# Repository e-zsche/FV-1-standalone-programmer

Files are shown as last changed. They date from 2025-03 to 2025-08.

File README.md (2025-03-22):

# Micropython FV-1 flasher

Small project for flashing 24LC32A EEPROMs using any microcontroller which has enough flash and
is able to run Micropython. Just because, a raspberry pico is used.

<p float="left">
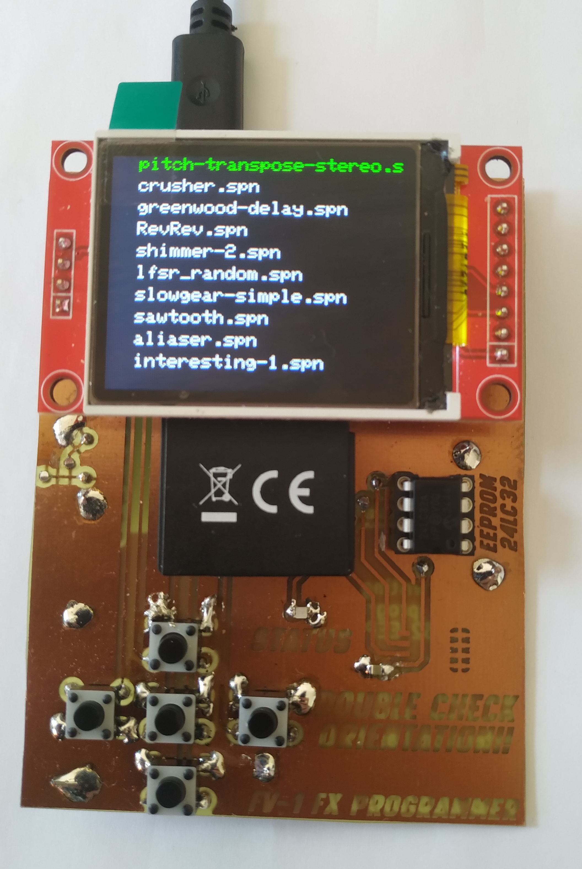
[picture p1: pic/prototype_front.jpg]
  
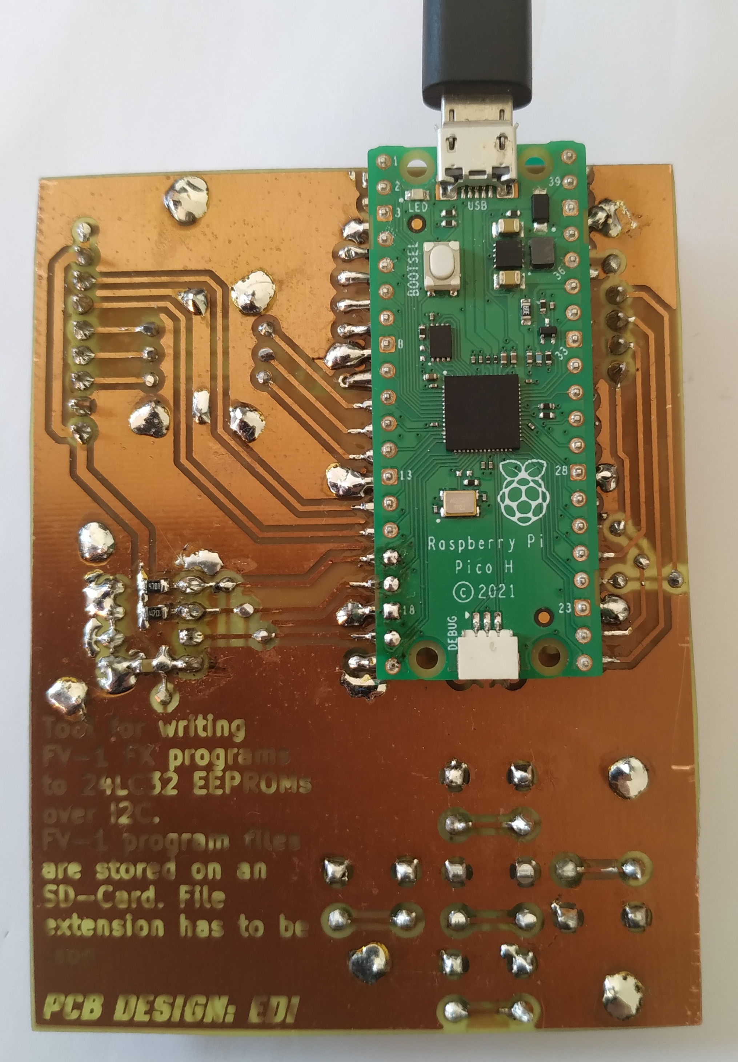
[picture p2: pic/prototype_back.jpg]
  
</p>

# Code

Huge thanks to ndf-zz for writing the asfv1 assembler. Without your work this would not be possible.
<https://github.com/ndf-zz/asfv1/>

As shlex is not in the standard Micropython library a copy of the source code is obtained and used
for running the asfv1 assembler. To get it running on the MCU one line is removed. So far this does
not seem to have an impact when running the code.

FV-1 programs are stored and read with a micro SD-card. All programs have to be in the root directory
and must have the `.spn` file extension to be found.

# Hardware

Everything is run by a Raspberry Pi Pico MCU.

User interface consists of:
- Display
- SD card slot
- EEPROM sockets
- Buttons

## Display

TFT display because it is cheaper than an OLED.
Has the SD card slot integrated.

## SD Card

Connected via SPI. Slot is Integrated into display module.

## EEPROM sockets

There are two positions on the PCB. One is for THT chips, the other for SMD chips.
SMD socket is the <a href="https://www.adafruit.com/product/4726">SOIC-8 socket from adafruit</a>

Make sure to insert the EEPROM with the correct orientation!!

## Buttons

In total there are five buttons arranged as a sort of D-Pad and a shift button.

Controls:
- up and down for scrolling through file list (faster scrolling when holding shift button)
- left and right for selecting program slot of selected file
- middle button
  * start programming (when not selecting slot)
  * selecting slot

# Obtain SPN files

Writing programs yourself for the FV-1 is good way to get some programs. Info on the assembly
language is a little harder to find than info on the FV-1 hardware. However there are some
sources inside a forum dating back to 2019:

- <a href="https://xenvn.com/threads/spin-fv-1-audio-effects.125">Spin FV-1 Audio Effects</a>
- <a href="https://xenvn.com/threads/spin-fv-1-instructions-and-syntax.122/">Spin FV-1 Instructions and Syntax</a>
- <a href="https://xenvn.com/threads/basics-of-the-lfos-in-the-spin-fv-1.123/">Basics of the LFOs in the Spin FV-1</a>

This is about all the info I could find on the assembly instructions itself...

Another wonderful source of programs is mstratman's collection of programs:

<https://mstratman.github.io/fv1-programs/>

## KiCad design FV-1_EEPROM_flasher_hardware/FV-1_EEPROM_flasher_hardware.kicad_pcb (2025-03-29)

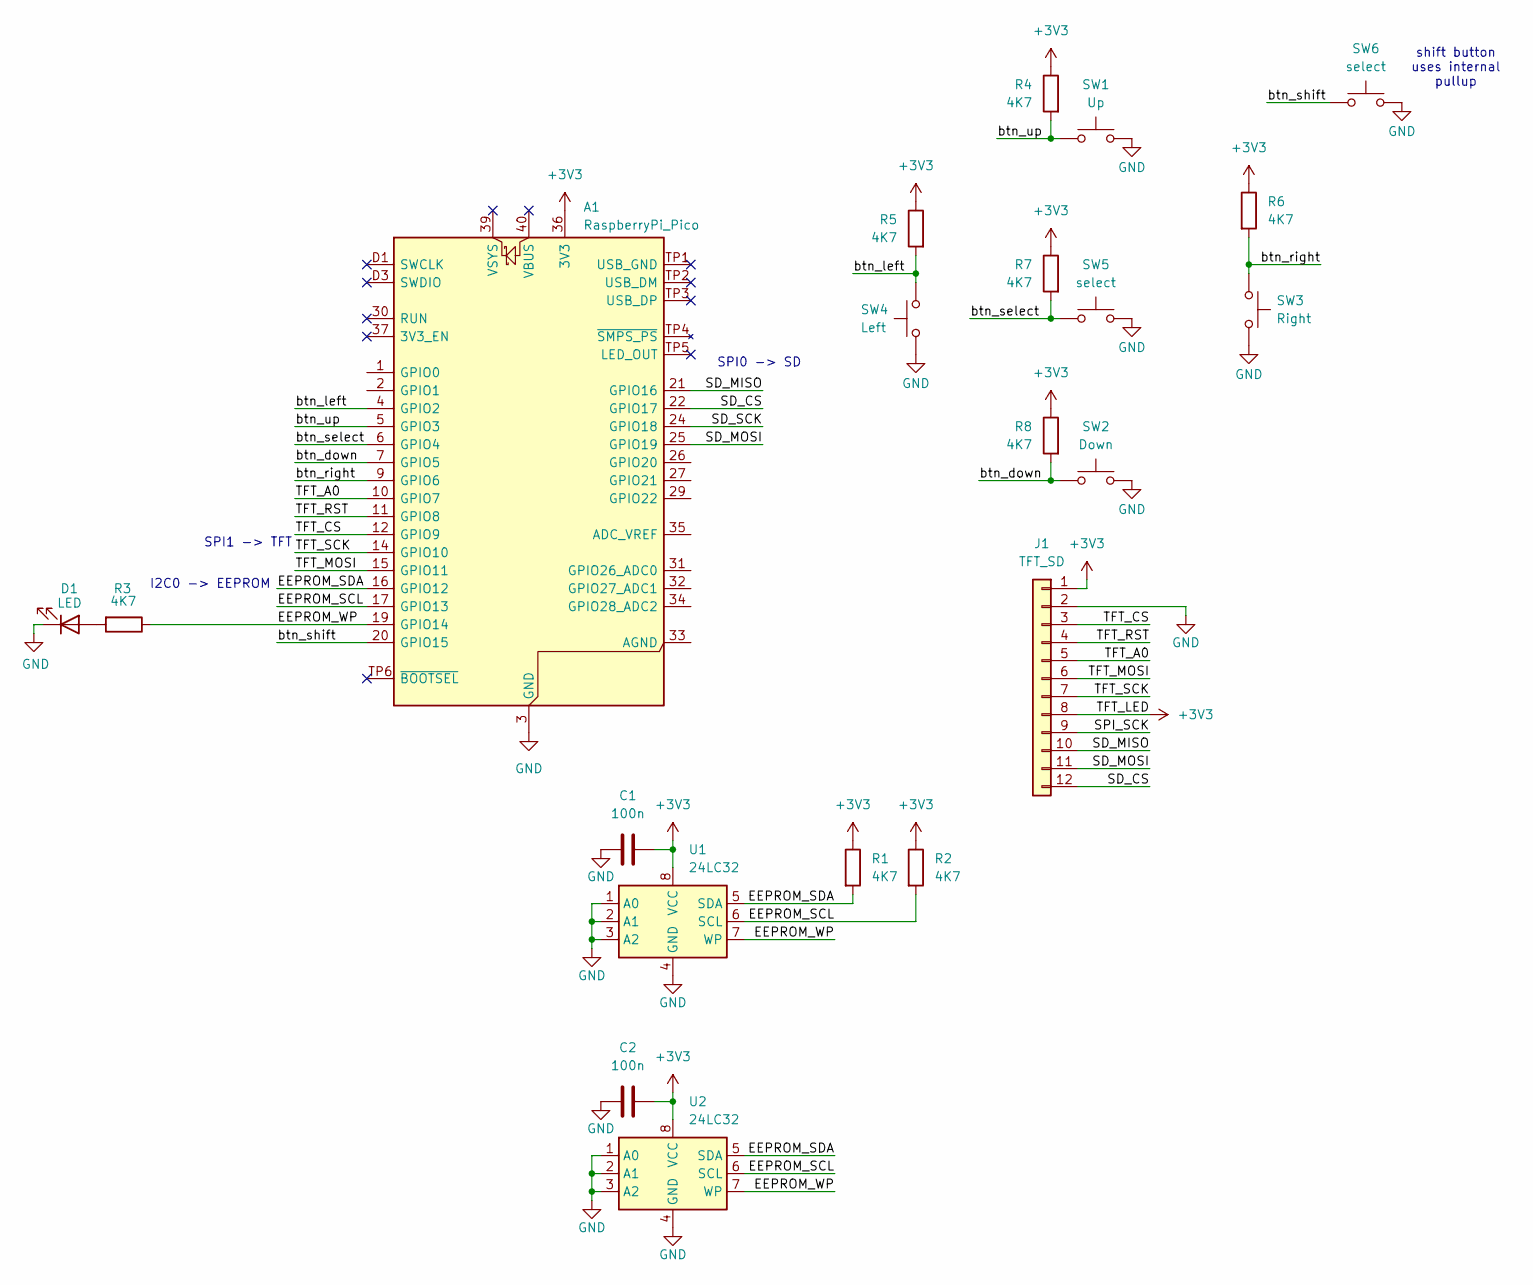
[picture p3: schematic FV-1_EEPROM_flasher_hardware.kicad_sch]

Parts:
A1: RaspberryPi_Pico; RaspberryPi_Pico_SMD
C1, C2: 100n; C_0805
D1: LED; LED_0805_2012Metric_Pad1.15x1.40mm_HandSolder
J1: TFT_SD; TFT_with_SD
R1, R2, R3, R4, R5, R6, R7, R8: 4K7; R_0805_2012Metric_Pad1.20x1.40mm_HandSolder
SW1: Up; SW_PUSH_6mm_H5mm
SW2: Down; SW_PUSH_6mm_H5mm
SW3: Right; SW_PUSH_6mm_H5mm
SW4: Left; SW_PUSH_6mm_H5mm
SW5, SW6: select; SW_PUSH_6mm_H5mm
U1: 24LC32; DIP-8_W7.62mm_Socket_LongPads
U2: 24LC32; SOIC-8_5.3x5.3mm_P1.27mm

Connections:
+3V3: A1.36 (3V3), C1.2, C2.2, J1.1, J1.8, R1.1, R2.1, R4.1, R5.1, R6.1, R7.1, R8.1, U1.8 (VCC), U2.8 (VCC)
/EEPROM_SCL: A1.17 (GPIO13), R2.2, U1.6 (SCL), U2.6 (SCL)
/EEPROM_SDA: A1.16 (GPIO12), R1.2, U1.5 (SDA), U2.5 (SDA)
/EEPROM_WP: A1.19 (GPIO14), R3.1, U1.7 (WP), U2.7 (WP)
/SD_CS: A1.22 (GPIO17), J1.12
/SD_MISO: A1.21 (GPIO16), J1.10
/SD_MOSI: A1.25 (GPIO19), J1.11
/SD_SCK: A1.24 (GPIO18)
/SPI_SCK: J1.9
/TFT_A0: A1.10 (GPIO7), J1.5
/TFT_CS: A1.12 (GPIO9), J1.3
/TFT_MOSI: A1.15 (GPIO11), J1.6
/TFT_RST: A1.11 (GPIO8), J1.4
/TFT_SCK: A1.14 (GPIO10), J1.7
/btn_down: A1.7 (GPIO5), R8.2, SW2.1
/btn_left: A1.4 (GPIO2), R5.2, SW4.2
/btn_right: A1.9 (GPIO6), R6.2, SW3.1
/btn_select: A1.6 (GPIO4), R7.2, SW5.1
/btn_shift: A1.20 (GPIO15), SW6.1
/btn_up: A1.5 (GPIO3), R4.2, SW1.1
GND: A1.3 (GND), A1.8 (GND), A1.13 (GND), A1.18 (GND), A1.23 (GND), A1.28 (GND), A1.38 (GND), A1.D2 (GND), C1.1, C2.1, D1.1 (K), J1.2, SW1.2, SW2.2, SW3.2, SW4.1, SW5.2, SW6.2, U1.1 (A0), U1.2 (A1), U1.3 (A2), U1.4 (GND), U2.1 (A0), U2.2 (A1), U2.3 (A2), U2.4 (GND)
unnamed: D1.2 (A), R3.2

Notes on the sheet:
I2C0 -> EEPROM
SPI1 -> TFT
SPI0 -> SD
shift button uses internal pullup

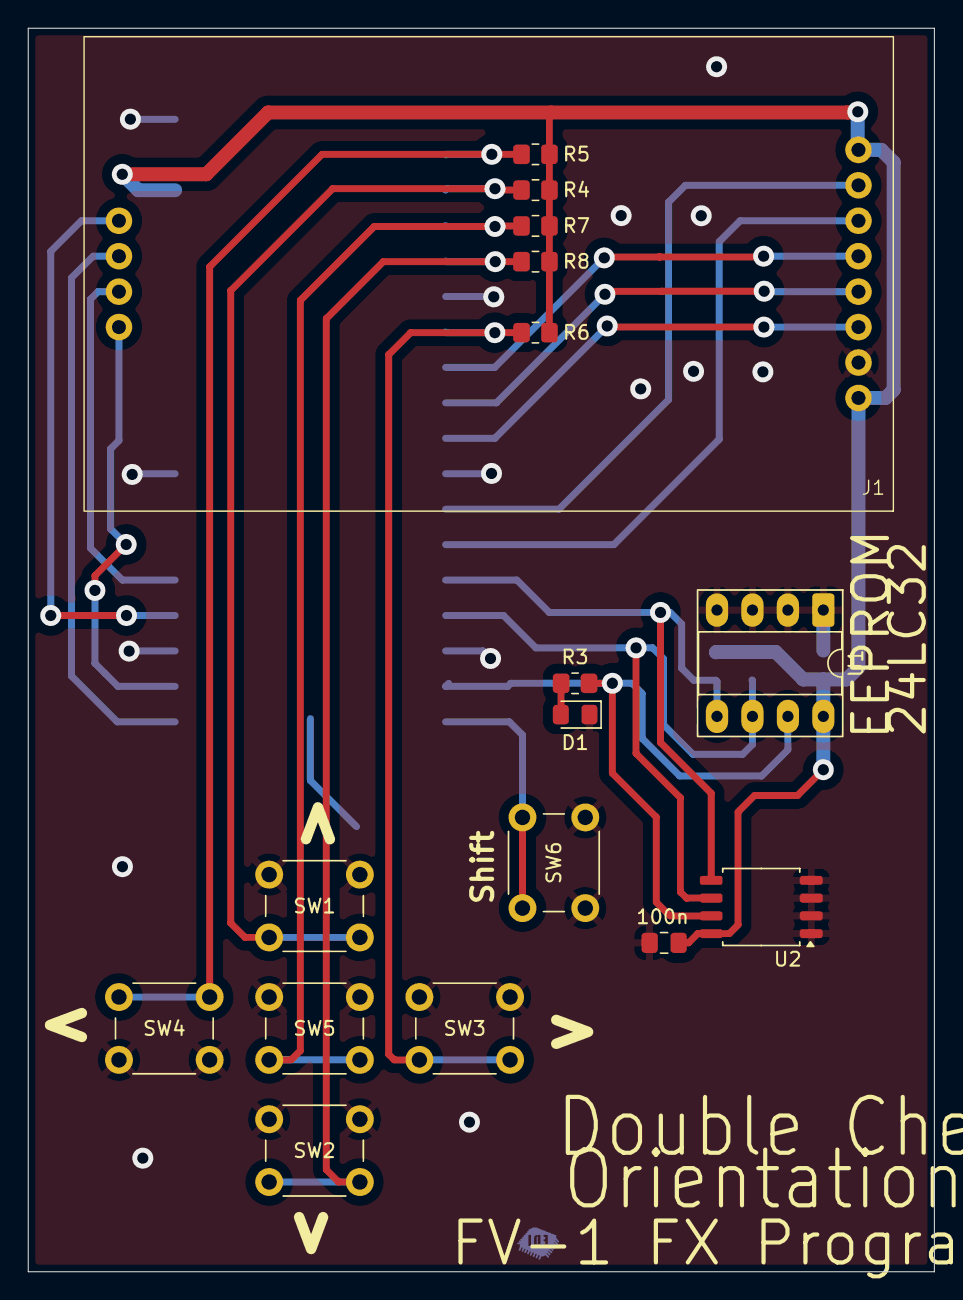
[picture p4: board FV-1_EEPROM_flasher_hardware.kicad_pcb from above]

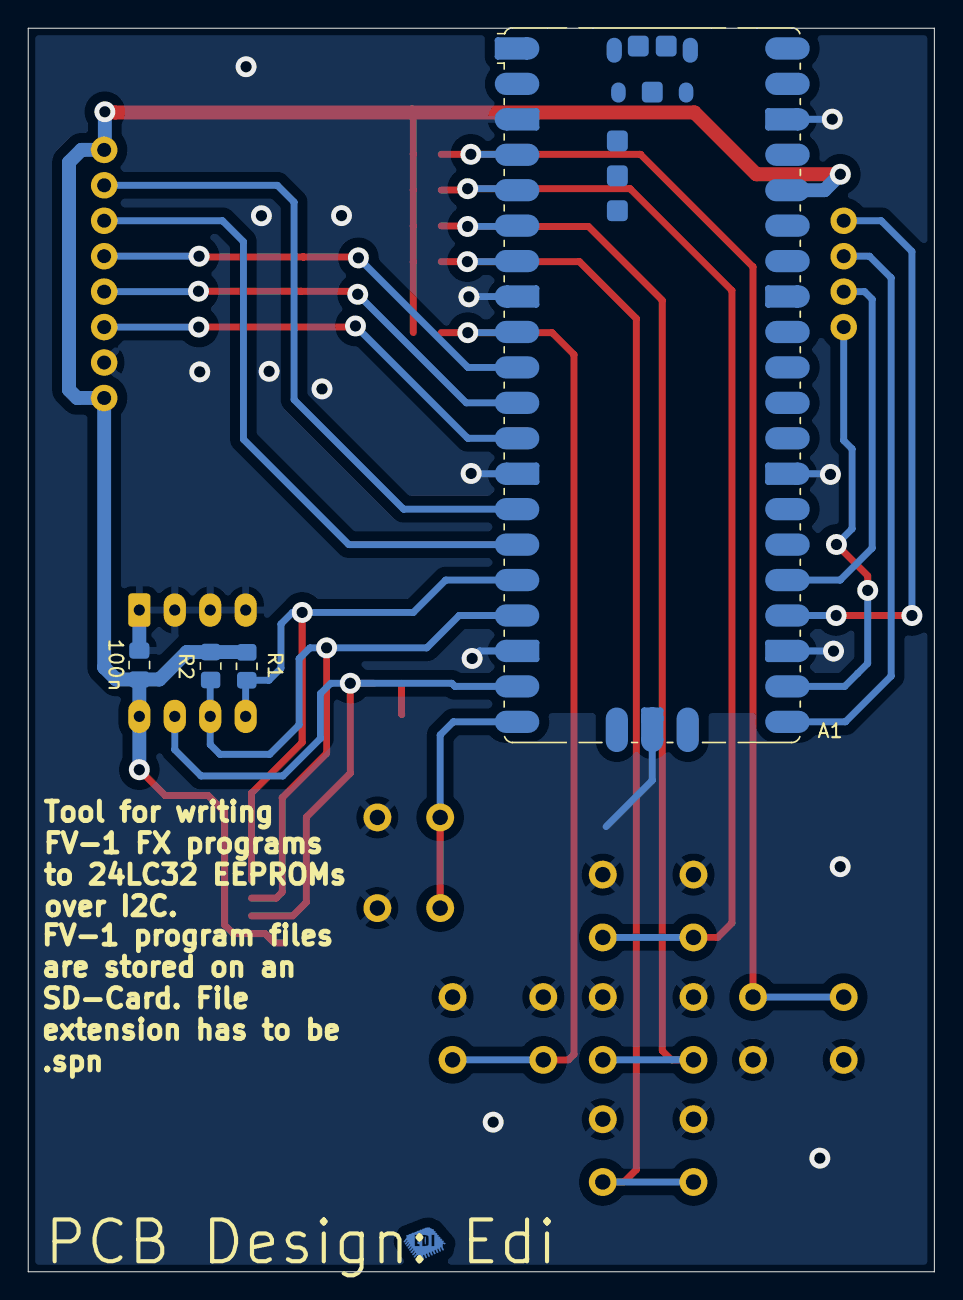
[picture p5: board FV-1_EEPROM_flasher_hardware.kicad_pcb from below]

Board: 2 copper layers, 64.9 x 89.1 mm, 22 parts (5 on the bottom side), 20 nets.

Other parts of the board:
Ref**: Val**; PCB_EDI_logo

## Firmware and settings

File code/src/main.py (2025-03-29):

import os
import time
import uos
import gc

from machine import Pin, SPI, I2C
from micropython import const  # type: ignore
from sysfont import sysfont

from lib import asfv1
from lib.ST7735 import TFT
from lib.sdcard import SDCard
from lib import widgets
from lib.EEPROM import EEPROM_24LC32A

CHAR_WIDTH = 6

TFT_WIDTH  = 160 # px
TFT_HEIGHT = 128 # px

btn_up      = Pin(3, Pin.IN, Pin.PULL_UP)
btn_down    = Pin(5, Pin.IN, Pin.PULL_UP)
btn_left    = Pin(2, Pin.IN, Pin.PULL_UP)
btn_right   = Pin(6, Pin.IN, Pin.PULL_UP)
btn_select  = Pin(4, Pin.IN, Pin.PULL_UP)
btn_shift   = Pin(15, Pin.IN, Pin.PULL_UP)

# TFT init
WHITE = const(0XFFFFFF)
tft_spi = SPI(1, baudrate=10000000, sck=Pin(10), mosi=Pin(11))
dc = 7; reset = 8; cs = 9;
tft = TFT(tft_spi, dc, reset, cs)
tft.rotation(3)
tft.initr()
tft.rgb(True)
tft.fill(TFT.BLACK)
tft.text(( 0,  1), "booting...", TFT.WHITE, sysfont, 1)

# EEPROM I2C
#eeprom_i2c = I2C(0, scl=Pin(13), sda=Pin(12))
eeprom = EEPROM_24LC32A(scl=Pin(13), sda=Pin(12), wp=Pin(14, Pin.OUT))

# SD Card init
sd_spi = SPI(0, baudrate=2000000,
             polarity=0, phase=0, bits=8,
             sck=Pin(18), mosi=Pin(19), miso=Pin(16))
try:
    sd = SDCard(sd_spi, cs=Pin(17))
except OSError:
    tft.fill(TFT.BLACK)
    tft.text(( 1,  1), "ERROR:", TFT.RED, sysfont, 2)
    tft.text(( 1,  30), "no SD card found...", TFT.WHITE, sysfont, 1)
    tft.text(( 1,  42), "check the card", TFT.WHITE, sysfont, 1)
    while 1:
        pass

SPN_ROOT_DIR = "/sd"

vfs  = uos.VfsFat(sd)
os.mount(sd, SPN_ROOT_DIR)

global TXT_SIZE, Y_START

TXT_SIZE = 1
Y_START = 2

fv_files = [f for f in os.listdir(SPN_ROOT_DIR) if f.endswith(".spn")]
if len(fv_files) < 1:
    tft.fill(TFT.BLACK)
    tft.text(( 1,  1), "ERROR:", TFT.RED, sysfont, 2)
    tft.text(( 1,  30), "no .spn files found", TFT.WHITE, sysfont, 1)
    tft.text(( 1,  42), "check your SD card", TFT.WHITE, sysfont, 1)
    tft.text(( 1,  54), "and retry", TFT.WHITE, sysfont, 1)
    while 1:
        pass

cursor_pos = 0
MAX_FILE_ON_DISP = 9
file_list_offs = [0, MAX_FILE_ON_DISP]

slot_pos = 0
fv_program_slots = {
        0: "",
        1: "",
        2: "",
        3: "",
        4: "",
        5: "",
        6: "",
        7: "",
        }

def draw_file_list():
    Y_START = 1
    for y_offs, name in enumerate(fv_files[ file_list_offs[0] : file_list_offs[1]+1 ]):
        color = TFT.WHITE
        if name in fv_program_slots.values():
            # TODO: show the slot
            inv_map = {v: k for k, v in fv_program_slots.items()}
            tft.text(( 1,  Y_START ), str(inv_map[name]+1), color, sysfont, TXT_SIZE, nowrap=True)
            pass
        if y_offs + file_list_offs[0] == cursor_pos:
            # highlight selected file
            color = TFT.GREEN
        tft.text(( 15,  Y_START ), name, color, sysfont, TXT_SIZE, nowrap=True)
        Y_START += 4+TXT_SIZE*8


############################
# MAIN
############################

# TODO: make a menu

tft.fill(TFT.BLACK)
draw_file_list()

print(file_list_offs)

# TODO: main loop
last_ticks_btn = 0
last_ticks_slot_blink = 0

is_slot_selection = False
sel_blink = False
slot_to_change = 0
while(1):
    #####################
    # SCROLL FILES
    #####################
    scroll_mul = 1
    if not is_slot_selection and time.ticks_ms() - last_ticks_btn > 250 and btn_down.value() == 0:
        tft.fill(TFT.BLACK)
        # scroll down
        if btn_shift.value() == 0:
            scroll_mul = MAX_FILE_ON_DISP

        cursor_pos += 1 * scroll_mul

        if cursor_pos > file_list_offs[1]:
            file_list_offs[0] = file_list_offs[0] + 1 * scroll_mul
            file_list_offs[1] = file_list_offs[1] + 1 * scroll_mul

        if file_list_offs[1] > len(fv_files)-1:
            # roll over to beginning
            file_list_offs[0] = 0
            file_list_offs[1] = MAX_FILE_ON_DISP

        if cursor_pos > len(fv_files)-1:
            cursor_pos = 0

        # redraw screen
        draw_file_list()
        # update btn debounce
        last_ticks_btn = time.ticks_ms()
        print(f"scroll down: cursor_pos {cursor_pos} | f: {fv_files[cursor_pos]}")

    if not is_slot_selection and time.ticks_ms() - last_ticks_btn > 250 and btn_up.value() == 0:
        tft.fill(TFT.BLACK)
        print(f"start scroll:\ncursor_pos: {cursor_pos}\noffs[0]: {file_list_offs[0]}\noffs[1]: {file_list_offs[1]}")
        # scroll up
        if btn_shift.value() == 0:
            scroll_mul = MAX_FILE_ON_DISP

        cursor_pos = cursor_pos - 1 * scroll_mul
        print(f"decrease cursor_pos: cursor_pos: {cursor_pos}")

        if cursor_pos < file_list_offs[0]:
            file_list_offs[0] = file_list_offs[0] - 1 * scroll_mul
            print(f"decrease index[0]: {file_list_offs[0]}")
            file_list_offs[1] = file_list_offs[1] - 1 * scroll_mul
            print(f"decrease index[1]: {file_list_offs[1]}")

        if file_list_offs[0] < 0:
            # roll over
            file_list_offs[0] = len(fv_files)-1 - MAX_FILE_ON_DISP
            file_list_offs[1] = len(fv_files)-1
            print("roll over")
            print(f"index[0]: {file_list_offs[0]}")
            print(f"index[1]: {file_list_offs[1]}")

        if cursor_pos < 0:
            print(f"cursor_pos: {cursor_pos}")
            cursor_pos = len(fv_files)-1

        draw_file_list()
        # update btn debounce
        last_ticks_btn = time.ticks_ms()
        print(f"scroll up: cursor_pos {cursor_pos} | f: {fv_files[cursor_pos]}")

    #####################
    # SLOT SELECTION
    #####################

    if is_slot_selection and time.ticks_ms() - last_ticks_btn > 250 and btn_select.value() == 0:
        # select program for slot
        if not slot_pos == -1:
            # check for duplicates
            if fv_files[cursor_pos] in fv_program_slots.values():
                print("program in use")
                # delete occurence
                for k in fv_program_slots.keys():
                    if fv_program_slots[k] == fv_files[cursor_pos]:
                        fv_program_slots[k] = ""
            fv_program_slots[slot_pos] = fv_files[cursor_pos]
            print(f"slot {slot_pos}: {fv_files[cursor_pos]}")
        if slot_pos == -1 and fv_files[cursor_pos] in fv_program_slots.values():
            # delete slot
            print(f"delete slot")
            for k in fv_program_slots.keys():
                if fv_program_slots[k] == fv_files[cursor_pos]:
                    fv_program_slots[k] = ""
        print(fv_program_slots)
        is_slot_selection = False
        print("stop slot selection")
        tft.fill(TFT.BLACK)
        draw_file_list()
        last_ticks_btn = time.ticks_ms()

    if is_slot_selection and time.ticks_ms() - last_ticks_slot_blink > 200:
        pos = (2, Y_START+(cursor_pos-file_list_offs[0])*TXT_SIZE*11+4)
        # blink slot selection num
        if sel_blink and slot_pos >= 0:
            color = TFT.GREEN
            if fv_program_slots[slot_pos] != "":
                color = TFT.YELLOW
            tft.text(pos, f"{slot_pos+1}", color, sysfont, TXT_SIZE)
        elif sel_blink and slot_pos == -1:
            tft.text(pos, "-", TFT.WHITE, sysfont, TXT_SIZE)
        else:
            tft.fillrect(pos, (10,10), TFT.BLACK)
        sel_blink = not sel_blink
        last_ticks_slot_blink = time.ticks_ms()

    # change slot of program
    if time.ticks_ms() - last_ticks_btn > 250 and btn_left.value() == 0:
        if not is_slot_selection:
            is_slot_selection = True
        else:
            slot_pos = slot_pos-1
        if slot_pos < -1:
            slot_pos = 7
        last_ticks_btn = time.ticks_ms()

    if time.ticks_ms() - last_ticks_btn > 250 and btn_right.value() == 0:
        if not is_slot_selection:
            is_slot_selection = True
        else:
            slot_pos = slot_pos+1
        if slot_pos > 7:
            slot_pos = -1
        last_ticks_btn = time.ticks_ms()

    #####################
    # PROGRAM EEPROM
    #####################
    if not is_slot_selection and time.ticks_ms() - last_ticks_btn > 250 and btn_select.value() == 0:
        # program eeproms as blocking call
        tft.fill(TFT.BLACK)
        has_eeprom = True
        if len(eeprom.i2c.scan()) == 0:
            has_eeprom = False
        if not len([i for i in fv_program_slots.values() if i ==""]) >= 8 and has_eeprom:
            print("start programming")
            eeprom_addr = eeprom.i2c.scan()[0]
            # something in dict
            for slot in range(8):
                txt_pos = (1, 2+slot*10)
                if fv_program_slots[slot] == "":
                    tft.text(txt_pos, f"slot{slot+1} empty", TFT.WHITE, sysfont, 1)
                    continue
                print(f"slot {slot}: {fv_program_slots[slot]}")
                spn_content = b""
                gc.collect() # free some RAM for this!
                with open(f"{SPN_ROOT_DIR}/{fv_program_slots[slot]}", "rb") as f:
                    try:
                        for line in f.readlines():
                            if line.startswith(b";") \
                                or line.startswith(b"\r") \
                                or line.startswith(b"\n"):
                                continue
                            spn_content += line.split(b";")[0]
                    except MemoryError:
                        # TODO: wat to do with Error
                        print("MemoryError: file content too big for RAM")
                        tft.text(txt_pos, f"slot{slot+1} ERROR:file too big!", TFT.RED, sysfont, 1)
                        continue

                encoding = 'utf-8'
                # check for BOM
                if len(spn_content) > 2 and spn_content[0] == 0xFF and spn_content[1] == 0xFE:
                    encoding = 'utf-16le'
                elif len(spn_content) > 2 and spn_content[0] == 0xFE and spn_content[1] == 0xFF:
                    encoding = 'utf-16be'
                # or assume windows encoded 'ANSI'
                elif len(spn_content) > 7 and spn_content[7] == 0x00:
                    encoding = 'utf-16le'

                fv1_parser = asfv1.fv1parse(spn_content.decode(encoding, 'replace'),
                                            clamp=True, spinreals=True,
                                            wfunc=asfv1.warning, efunc=asfv1.error
                                           )
                for attempt in range(3):
                    try:
                        fv1_parser.parse()
                    except asfv1.ASFV1Error:
                        if attempt == 0:
                            fv1_parser.doclamp = False
                            fv1_parser.spinreals = True
                        elif attempt == 1:
                            fv1_parser.doclamp = True
                            fv1_parser.spinreals = False
                        elif attempt == 2:
                            fv1_parser.doclamp = False
                            fv1_parser.spinreals = False
                        print("assembler error. trying again")
                        continue
                    else:
                        # reset to startign flags
                        print("did work now")
                        fv1_parser.doclamp = True
                        fv1_parser.spinreals = True
                        break
                else:
                    # TODO: program does not assemble
                    tft.text(txt_pos, f"slot{slot+1} ERROR:file not valid!", TFT.RED, sysfont, 1)
                    continue

                # write to EEPROM
                mem_offs = 0x200 * slot
                eeprom.write_data(mem_offs, fv1_parser.program)
                if fv1_parser.program == eeprom.read_data(mem_offs, 0x200):
                    print("program check OK!")
                    tft.text(txt_pos, f"slot{slot+1} okay!", TFT.WHITE, sysfont, 1)
                else:
                    tft.text(txt_pos, f"slot{slot+1} ERROR:not written!", TFT.RED, sysfont, 1)

                # free RAM so it does not fill while assembling
                del spn_content
                del fv1_parser
                gc.collect() # free some RAM for this!

            tft.text((10, txt_pos[1]+22), f"press select button", TFT.YELLOW, sysfont, 1)
            tft.text((10, txt_pos[1]+34), f"to continue", TFT.YELLOW, sysfont, 1)
            while btn_select.value():
                pass
        elif len([i for i in fv_program_slots.values() if i ==""]) >= 8:
            print("no files selected")
            # dict empty
            tft.text((2, 10), "No", TFT.RED, sysfont, 3)
            tft.text((2, 40), "programs", TFT.RED, sysfont, 3)
            tft.text((2, 70), "selected", TFT.RED, sysfont, 3)
            time.sleep(3)
        elif not has_eeprom:
            print("no eeprom found")
            tft.text((2, 10), "No", TFT.RED, sysfont, 3)
            tft.text((2, 40), "EEPROM", TFT.RED, sysfont, 3)
            tft.text((2, 70), "found", TFT.RED, sysfont, 3)
            time.sleep(3)

        # reset to selection screen
        tft.fill(TFT.BLACK)
        draw_file_list()
        last_ticks_btn = time.ticks_ms()

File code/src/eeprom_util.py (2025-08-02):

from machine import Pin, I2C
import time

wp = Pin(14, Pin.OUT)
wp.on()
i2c = I2C(0, scl=Pin(13), sda=Pin(12))

def read_eeprom(mem_addr, num_bytes):
    return i2c.readfrom_mem(0x50, mem_addr, num_bytes, addrsize=16)

def read_program(num_program):
    if num_program < 1 or num_program > 8:
        print("program number must be between 1 or 8")
        return
    return read_eeprom(0x200*(num_program-1), 0x200)

def write_eeprom(mem_addr, byte_buf):
    if len(byte_buf) < 32:
        wp.off()
        i2c.writeto_mem(0x50, mem_addr, byte_buf, addrsize=16)
        wp.on()
        return

    curr_idx = 0
    n_slices = int(len(byte_buf)/32)
    for i in range(n_slices):
        mem_offs = mem_addr + i*32
        wp.off()
        i2c.writeto_mem(0x50, mem_offs, byte_buf[curr_idx:curr_idx+32], addrsize=16)
        wp.on()
        curr_idx += 32
        time.sleep(0.005) # 5ms wait time needed by eeprom
    i+=1
    mem_offs = mem_addr + i*32
    wp.off()
    i2c.writeto_mem(0x50, mem_offs, byte_buf[curr_idx:curr_idx+32], addrsize=16)
    print(curr_idx)
    wp.on()

def clone_eeprom():
    print("reading from eeprom")

    if not 0x50 in i2c.scan():
        print("no eeprom found. Aborting")
        return

    if input("start cloning [y/N]").lower() not in ["y", "yes"]:
        print("Aborting")
        return

    # read all programs
    content = b""
    for i in range(8):
        content += read_eeprom(i*0x200, 0x200)
    print("read successful")

    if input("insert empty EEPROM and continue [y/N]").lower() not in ["y", "yes"]:
        print("Aborting")
        return

    write_eeprom(0, content)

    print("checking content")
    content2 = b""
    for i in range(8):
        content2 += read_eeprom(i*0x200, 0x200)

    if not content == content2:
        print("ERROR: data verification failed")
        return

    print("SUCCESS: data verified and EEPROM is cloned")

def show_content():
    doc_str = """
    available functions:
      show_content()
        show this help text

      read_eeprom(mem_addr:int, num_bytes:int) -> bytes
        reads and returns num_bytes from eeprom starting at address mem_addr

      write_eeprom(mem_addr:int, byte_buf:bytes)
        writes bytes from byte_buf to eeprom starting at address mem_addr

      read_program(num_program) -> bytes
        read FV-1 program from EEPROM. num_program must be between 1 to 8

      clone_eeprom()
        clone EEPROM content two another EEPROM
    """
    print(doc_str)

show_content()

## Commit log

2025-03-18 added kicad hardware folder
    [FV-1_EEPROM_flasher_hardware.kicad_pcb, FV-1_EEPROM_flasher_hardware.kicad_sch]
2025-03-18 added uf2 binary for rpi pico
2025-03-18 removed unused SD card symbols
    [FV-1_EEPROM_flasher_hardware.kicad_sch]
2025-03-18 rewrote i2c_util.py to eeprom_util.py for easier usage
2025-03-18 error on tft when file is too big for RAM
    [main.py]
2025-03-18 bugfix: free RAM after assembling and writing program
    [main.py]
2025-03-18 replaced status led with shift button, led connected to EEPROM write protect pin
    [FV-1_EEPROM_flasher_hardware.kicad_pcb, FV-1_EEPROM_flasher_hardware.kicad_sch]
2025-03-18 use shift button for faster scrolling
2025-03-18 binary with shift button
2025-03-21 BUGFIX: fast scrolling was broken
    [main.py]
2025-03-21 fixed missing screen update when rolling over file list
    [main.py]
2025-03-29 fixed scrolling, added SD card error messages
    [main.py]
2025-03-29 flipped EEPROM socket by 90°; PCB ready for production
    [FV-1_EEPROM_flasher_hardware.kicad_pcb]
2025-03-29 binary for rpi pico up to date
2025-08-02 BUGFIX: fixed wrong array indexing in write_eeprom function
    [eeprom_util.py]
